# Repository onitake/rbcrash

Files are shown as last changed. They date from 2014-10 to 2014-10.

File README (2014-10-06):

Rainbow Crash
=============

Colorful illumination - it's 20% cooler.

0. Contents
-----------

0. Contents
1. Description
2. License
3. Tools
4. Assembly
5. Compilation
6. Use
7. References

1. Description
--------------

Rainbow Crash is a high power color LED driver suitable for indoor lighting
applications. It is based on the TPS61165 constant current step-up regulator,
driving a chain of 350mA RGB LEDs. In the default configuration, the input
voltage should be around 12V for 8 LEDs in series. Lower voltages are possible,
as long as they are not below about 4V, or the microcontroller and the drivers
will be underpowered. Higher voltages should only be chosen if more than 8 LEDs
are driven.

2. License
----------

The circuit design is released under the [CERN Open Hardware License v1.2][ohl].
The firmware is covered by the [two-clause BSD license][bsd].

All documents are copyright (c) 2012-2014 by Gregor Riepl <onitake@gmail.com>.

The latest version can be retrieved from [Github][github].

3. Tools
--------

The original circuit was designed using [Eagle][eagle]. An updated version of
the circuit (2.0) was remade in [KiCAD][kicad].
The firmware for the microcontroller is based on a simple Makefile,
[avr-gcc][avrgcc], avr-libc and [avrdude][avrdude].
The code should be easily adaptable to other Atmel toolchains.

No [Arduino][arduino] or other external libraries were used; however, the code
includes register definitions for the [Arduino Uno][uno] development platform.
It was during the design phase and for debugging.

4. Assembly
-----------

Except for the constant current drivers and the corresponding inductors, most
parts should be easily obtainable from any electronic parts distributor.
Some of the capacitors are also less common (10uF and 4.7uF SMD0805 ceramic),
as well as the shunt resistors (0.57Ohms 1/8W).
SMD0805/2012 was chosen due to good hand solderability and power rating.

The inductor pads are generously dimensioned so they may accomodate various
kinds of SMD inductors. The layout is based on Wuerth Electronics WE-PD M-sized
shielded inductors, which are readily available from [Digi-Key][digikey].
Their continuous current rating should be above 700mA, preferably around 1A.

The intended IR receiver is a standard 38kHz demodulator with AGC. Other
parts with similar specifications may be used; they are mostly compatible
with each other and various consumer remotes.

It is recommended to employ a reflow process if producing multiple driver
boards. For single pieces or prototypes, hand soldering is also possible.

Production runs should not include the ISP pin header P6. Instead, order the
ATtiny25 microcontrollers preprogrammed or use a temporary connector to
transfer the firmware.

5. Compilation
--------------

All source code is contained in the single file pwm.c. Compiling is easiest
with the [avr-gcc][avrgcc] toolchain and GNU make. If you would like to use
other tools, make sure that your compiler understands ISO C99.

To flash the firmware, the Makefile includes a `flash` target that executes
[avrdude][avrdude] using options for the tinyUSB AVR ISP programmer.
avrdude supports many different programmers, see the manual for the appropriate
options.

6. Use
------

pwm.c includes preprogrammed IR codes for an old infrared remote found in the
garbage. It sends (incorrect) NEC codes, so those are the only IR codes
currently supported by the firmware. Sony and RC5 codes are still being worked
on, as well as a test tool for the Arduino Uno and possibly a firmware
extension to support live programming.

7. References
-------------

[ohl]: LICENSE-HARDWARE
[bsd]: LICENSE-SOFTWARE
[github]: https://github.com/onitake/rbcrash
[eagle]: http://www.cadsoft.de
[kicad]: http://www.kicad-pcb.org
[arduino]: http://arduino.cc
[uno]: http://arduino.cc/en/Main/ArduinoBoardUno
[digikey]: http://www.digikey.com/catalog/en/partgroup/we-pd-series/38220
[avrgcc]: http://www.nongnu.org/avr-libc/
[avrdude]: http://www.nongnu.org/avrdude/

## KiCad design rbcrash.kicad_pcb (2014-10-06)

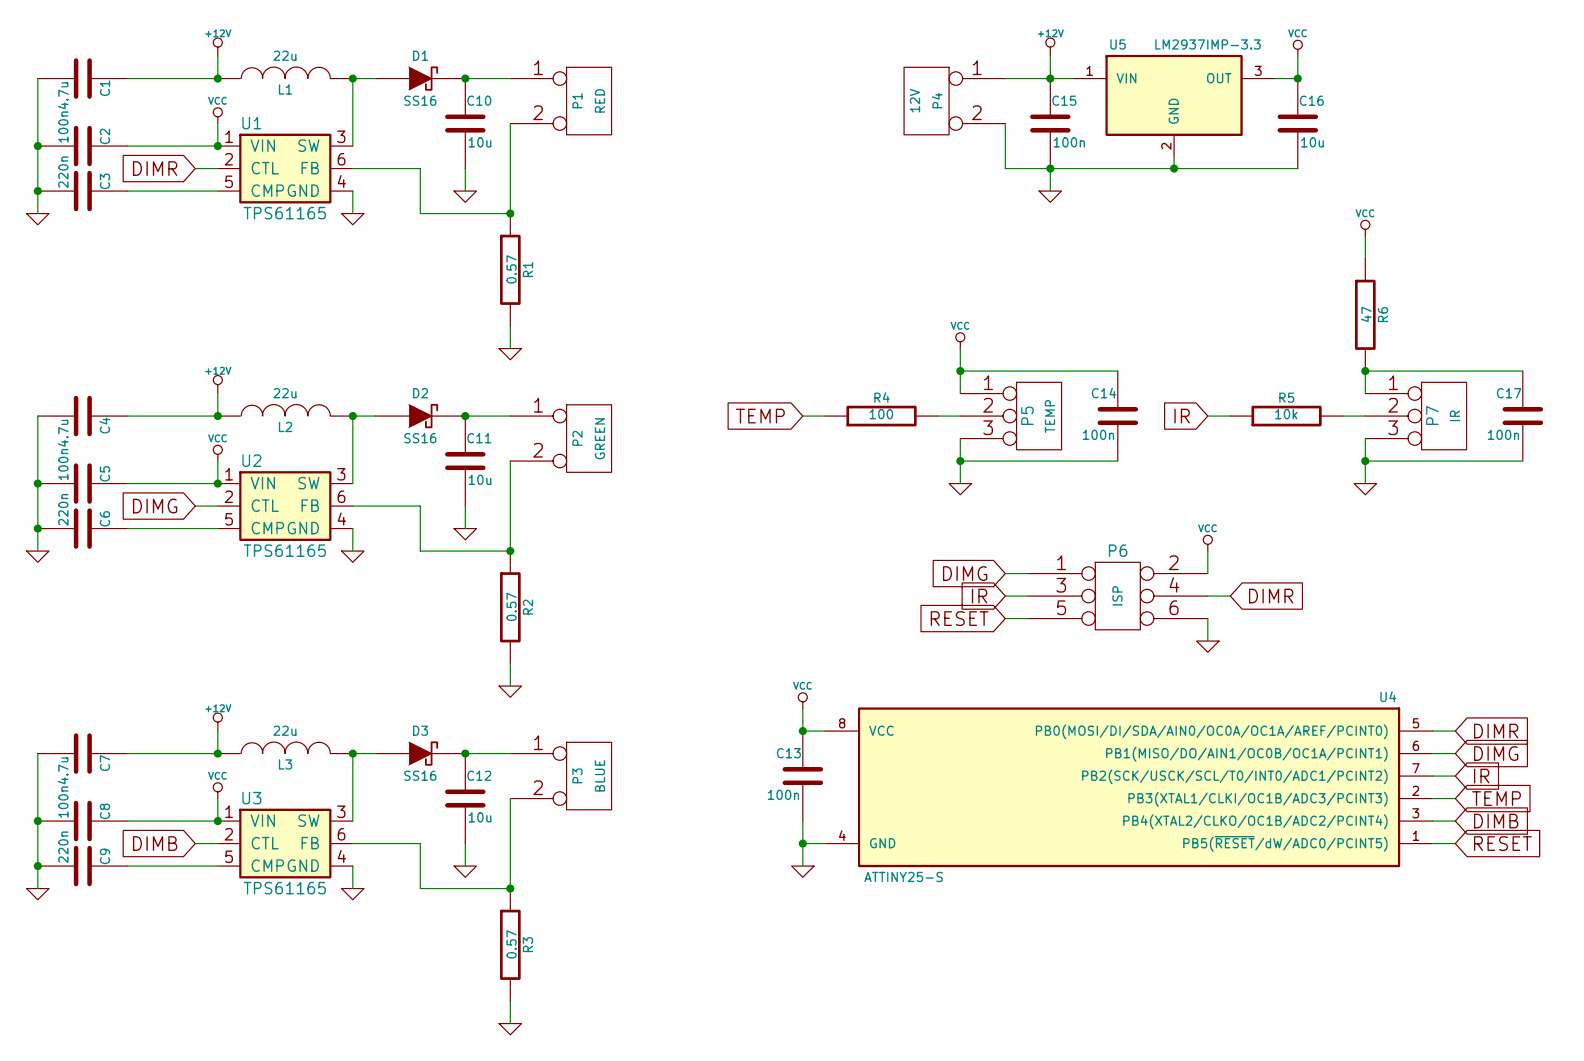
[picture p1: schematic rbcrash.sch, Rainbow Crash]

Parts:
C1, C4, C7: 4.7u; SM0805
C2, C5, C8, C13, C14, C15, C17: 100n; SM0805
C3, C6, C9: 220n; SM0805
C10, C11, C12, C16: 10u; SM0805
D1, D2, D3: SS16
L1, L2, L3: 22u
P1: RED
P2: GREEN
P3: BLUE
P4: 12V
P5: TEMP
P6: ISP
P7: IR
R1, R2, R3: 0.57; SM0805
R4: 100; SM0805
R5: 10k; SM0805
R6: 47; SM0805
U1, U2, U3: TPS61165
U4: ATTINY25-S; SO8-200
U5: LM2937IMP-3.3; SOT-223

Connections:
+12V: C1.1, C4.1, C7.1, C15.1, L1.1, L2.1, L3.1, P4.1, U5.1 (VIN)
DIMB: U3.2 (CTL), U4.3 (PB4(XTAL2/CLKO/OC1B/ADC2/PCINT4))
DIMG: P6.1, U2.2 (CTL), U4.6 (PB1(MISO/DO/AIN1/OC0B/OC1A/PCINT1))
DIMR: P6.4, U1.2 (CTL), U4.5 (PB0(MOSI/DI/SDA/AIN0/OC0A/OC1A/AREF/PCI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)
GND: C1.2, C2.2, C3.2, C4.2, C5.2, C6.2, C7.2, C8.2, C9.2, C10.2, C11.2, C12.2, C13.2, C14.2, C15.2, C16.2, C17.2, P4.2 (PM), P5.3, P6.6, P7.3, R1.2, R2.2, R3.2, U1.4 (GND), U2.4 (GND), U3.4 (GND), U4.4 (GND), U5.2 (GND)
IR: P6.3, R5.1, U4.7 (PB2(SCK/USCK/SCL/T0/INT0/ADC1/PCINT2))
unnamed: C12.1, D3.2 (K), P3.1
unnamed: C9.1, U3.5 (CMP)
unnamed: P3.2 (PM), R3.1, U3.6 (FB)
unnamed: D3.1 (A), L3.2, U3.3 (SW)
unnamed: P2.2 (PM), R2.1, U2.6 (FB)
unnamed: C6.1, U2.5 (CMP)
unnamed: C11.1, D2.2 (K), P2.1
unnamed: D2.1 (A), L2.2, U2.3 (SW)
unnamed: C17.1, P7.1, R6.2
unnamed: P7.2 (PM), R5.2
unnamed: P5.2 (PM), R4.2
unnamed: C3.1, U1.5 (CMP)
unnamed: C10.1, D1.2 (K), P1.1
unnamed: P1.2 (PM), R1.1, U1.6 (FB)
unnamed: D1.1 (A), L1.2, U1.3 (SW)
RESET: P6.5, U4.1 (PB5(~RESET~/dW/ADC0/PCINT5))
TEMP: R4.1, U4.2 (PB3(XTAL1/CLKI/OC1B/ADC3/PCINT3))
VCC: C2.1, C5.1, C8.1, C13.1, C14.1, C16.1, P5.1, P6.2, R6.1, U1.1 (VIN), U2.1 (VIN), U3.1 (VIN), U4.8 (VCC), U5.3 (OUT)

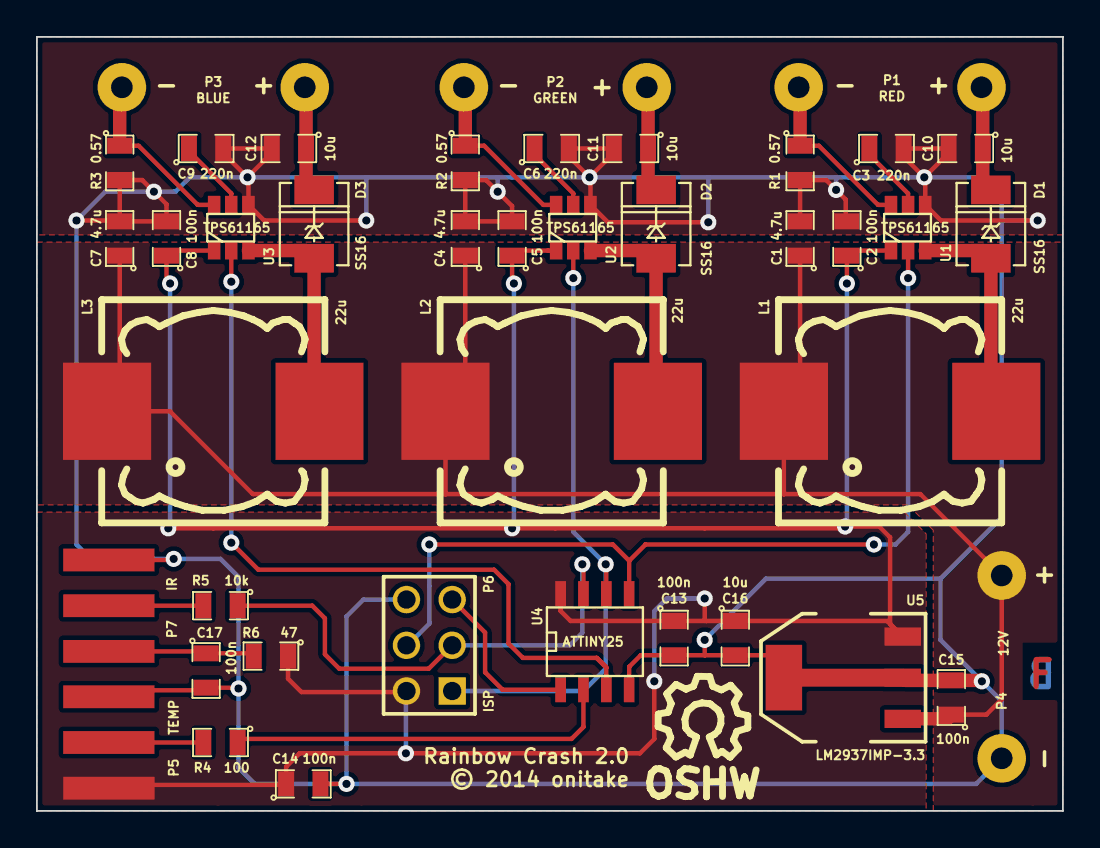
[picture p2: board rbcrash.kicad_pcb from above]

Board: 2 copper layers, 57.0 x 43.0 mm, 42 parts (0 on the bottom side), 24 nets.

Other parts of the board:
SYM: Symbol_OSHW-Logo_SilkScreen_07Jul2012

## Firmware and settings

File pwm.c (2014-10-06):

/*
 * rbcrash - Rainbow Crash LED driver firmware
 * 
 * Copyright (c) 2012-2014, Gregor Riepl <onitake@gmail.com>
 * All rights reserved.
 * 
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
 * THIS SOFTWARE IS PROVIDED BY THE COPYRIGHT HOLDERS AND CONTRIBUTORS "AS IS" AND
 * ANY EXPRESS OR IMPLIED WARRANTIES, INCLUDING, BUT NOT LIMITED TO, THE IMPLIED
 * WARRANTIES OF MERCHANTABILITY AND FITNESS FOR A PARTICULAR PURPOSE ARE
 * DISCLAIMED. IN NO EVENT SHALL THE COPYRIGHT HOLDER OR CONTRIBUTORS BE LIABLE FOR
 * ANY DIRECT, INDIRECT, INCIDENTAL, SPECIAL, EXEMPLARY, OR CONSEQUENTIAL DAMAGES
 * (INCLUDING, BUT NOT LIMITED TO, PROCUREMENT OF SUBSTITUTE GOODS OR SERVICES;
 * LOSS OF USE, DATA, OR PROFITS; OR BUSINESS INTERRUPTION) HOWEVER CAUSED AND ON
 * ANY THEORY OF LIABILITY, WHETHER IN CONTRACT, STRICT LIABILITY, OR TORT
 * (INCLUDING NEGLIGENCE OR OTHERWISE) ARISING IN ANY WAY OUT OF THE USE OF THIS
 * SOFTWARE, EVEN IF ADVISED OF THE POSSIBILITY OF SUCH DAMAGE.
 */

#include <inttypes.h>
#include <avr/io.h>
#include <avr/interrupt.h>
#include <avr/sleep.h>
#include <util/atomic.h>
#include <avr/io.h>
#include <util/delay.h>
#include <stdio.h>
#include <avr/pgmspace.h>
#include "clocks.h"

#if CLOCK_DIV >= 256 && CLOCK_DIV % 256 == 0
#define CLOCK0_DIV (CLOCK_DIV / 256)
#define CLOCK1_DIV (CLOCK_DIV / 256)
#define CLOCK_COUNT 1
#else
#error Invalid clock divider for IR decoder, an integer multiple of 256 is required
#endif

#ifdef F_IR_MIN
#if F_CPU / CLOCK0_DIV / 256 < F_IR_MIN
#error PWM frequency is too small, decrease the divider
#endif
#endif
#ifdef F_IR_MAX
#if F_CPU / CLOCK0_DIV / 256 > F_IR_MAX
#error PWM frequency is too big, increase the divider
#endif
#endif

#if defined(__AVR_ATtiny25__) || defined(__AVR_ATtiny45__) || defined(__AVR_ATtiny85__)

#if (CLOCK0_DIV == 0)
#define CLOCK0_CSX 0
#elif (CLOCK0_DIV == 1)
#define CLOCK0_CSX _BV(CS00)
#elif (CLOCK0_DIV == 8)
#define CLOCK0_CSX _BV(CS01)
#elif (CLOCK0_DIV == 64)
#define CLOCK0_CSX (_BV(CS00) | _BV(CS01))
#elif (CLOCK0_DIV == 256)
#define CLOCK0_CSX _BV(CS02)
#elif (CLOCK0_DIV == 1024)
#define CLOCK0_CSX (_BV(CS00) | _BV(CS02))
#else
#error Unsupported divider for timer 0
#endif

#define CLOCK0_TCCRA TCCR0A
#define CLOCK0_TCCRB TCCR0B
#define CLOCK0_TIMSK TIMSK
#define CLOCK0_TCNT TCNT0
#define CLOCK0_REGA (_BV(WGM00) | _BV(WGM01) | _BV(COM0A0) | _BV(COM0A1) | _BV(COM0B0) | _BV(COM0B1))
#define CLOCK0_REGB CLOCK0_CSX
#define CLOCK0_INTS _BV(TOIE0)
#define CLOCK0_OVERFLOW_INTVECT TIMER0_OVF_vect

#if (CLOCK1_DIV == 0)
#define CLOCK1_CSX 0
#elif (CLOCK1_DIV == 1)
#define CLOCK1_CSX _BV(CS10)
#elif (CLOCK1_DIV == 2)
#define CLOCK1_CSX _BV(CS11)
#elif (CLOCK1_DIV == 4)
#define CLOCK1_CSX (_BV(CS10) | _BV(CS11))
#elif (CLOCK1_DIV == 8)
#define CLOCK1_CSX _BV(CS12)
#elif (CLOCK1_DIV == 16)
#define CLOCK1_CSX (_BV(CS10) | _BV(CS12))
#elif (CLOCK1_DIV == 32)
#define CLOCK1_CSX (_BV(CS11) | _BV(CS12))
#elif (CLOCK1_DIV == 64)
#define CLOCK1_CSX (_BV(CS10) | _BV(CS11) | _BV(CS12))
#elif (CLOCK1_DIV == 128)
#define CLOCK1_CSX _BV(CS13)
#elif (CLOCK1_DIV == 256)
#define CLOCK1_CSX (_BV(CS10) | _BV(CS13))
#elif (CLOCK1_DIV == 512)
#define CLOCK1_CSX (_BV(CS11) | _BV(CS13))
#elif (CLOCK1_DIV == 1024)
#define CLOCK1_CSX (_BV(CS10) | _BV(CS11) | _BV(CS13))
#elif (CLOCK1_DIV == 2048)
#define CLOCK1_CSX (_BV(CS12) | _BV(CS13))
#elif (CLOCK1_DIV == 4096)
#define CLOCK1_CSX (_BV(CS10) | _BV(CS12) | _BV(CS13))
#elif (CLOCK1_DIV == 8192)
#define CLOCK1_CSX (_BV(CS11) | _BV(CS12) | _BV(CS13))
#elif (CLOCK1_DIV == 16384)
#define CLOCK1_CSX (_BV(CS10) | _BV(CS11) | _BV(CS12) | _BV(CS13))
#else
#error Unsupported divider for timer 1
#endif

#define CLOCK1_TCCRA TCCR1
#define CLOCK1_TCCRB GTCCR
#define CLOCK1_TIMSK TIMSK
#define CLOCK1_TCNT TCNT1
#define CLOCK1_REGA CLOCK1_CSX
#define CLOCK1_REGB (_BV(PWM1B) | _BV(COM1B0))
#define CLOCK1_INTS 0
#define CLOCK1_OVERFLOW_INTVECT TIMER2_OVF_vect

#define PWM_OCR_RED OCR0A
#define PWM_OCR_GREEN OCR0B
#define PWM_OCR_BLUE OCR1B
#define PWM_PORT PORTB
#define PWM_DDR DDRB
#define PWM_PIN PINB
#define PWM_MASK (_BV(0) | _BV(1) | _BV(4))
#define PWM_INV_RED 1
#define PWM_INV_GREEN 1
#define PWM_INV_BLUE 0

#define IR_PIN PINB
#define IR_DDR DDRB
#define IR_PORT PORTB
#define IR_BIT _BV(DDB2)
#define IR_INT _BV(PCINT2)
#define IR_PCMSK PCMSK
#define IR_GIMSK GIMSK
#define IR_PCIE _BV(PCIE)
#define IR_INTVECT PCINT0_vect

#elif defined(__AVR_ATmega328__) || defined(__AVR_ATmega328P__)

#if (CLOCK0_DIV == 0)
#define CLOCK0_CSX 0
#elif (CLOCK0_DIV == 1)
#define CLOCK0_CSX _BV(CS00)
#elif (CLOCK0_DIV == 8)
#define CLOCK0_CSX _BV(CS01)
#elif (CLOCK0_DIV == 64)
#define CLOCK0_CSX (_BV(CS00) | _BV(CS01))
#elif (CLOCK0_DIV == 256)
#define CLOCK0_CSX _BV(CS02)
#elif (CLOCK0_DIV == 1024)
#define CLOCK0_CSX (_BV(CS00) | _BV(CS02))
#else
#error Unsupported divider for timer 0
#endif

#define CLOCK0_TCCRA TCCR0A
#define CLOCK0_TCCRB TCCR0B
#define CLOCK0_TIMSK TIMSK0
#define CLOCK0_TCNT TCNT0
#define CLOCK0_REGA (_BV(WGM00) | _BV(WGM01) | _BV(COM0A0) | _BV(COM0A1) | _BV(COM0B0) | _BV(COM0B1))
#define CLOCK0_REGB CLOCK0_CSX
#define CLOCK0_INTS _BV(TOIE0)
#define CLOCK0_OVERFLOW_INTVECT TIMER0_OVF_vect

#if (CLOCK1_DIV == 0)
#define CLOCK1_CSX 0
#elif (CLOCK1_DIV == 1)
#define CLOCK1_CSX _BV(CS20)
#elif (CLOCK1_DIV == 8)
#define CLOCK1_CSX _BV(CS21)
#elif (CLOCK1_DIV == 32)
#define CLOCK1_CSX (_BV(CS20) | _BV(CS21))
#elif (CLOCK1_DIV == 64)
#define CLOCK1_CSX _BV(CS22)
#elif (CLOCK1_DIV == 128)
#define CLOCK1_CSX (_BV(CS20) | _BV(CS22))
#elif (CLOCK1_DIV == 256)
#define CLOCK1_CSX (_BV(CS21) | _BV(CS22))
#elif (CLOCK1_DIV == 1024)
#define CLOCK1_CSX (_BV(CS20) | _BV(CS21) | _BV(CS22))
#else
#error Unsupported divider for timer 1
#endif

#define CLOCK1_TCCRA TCCR2A
#define CLOCK1_TCCRB TCCR2B
#define CLOCK1_TIMSK TIMSK2
#define CLOCK1_TCNT TCNT2
#define CLOCK1_REGA (_BV(WGM20) | _BV(WGM21) | _BV(COM2B0) | _BV(COM2B1))
#define CLOCK1_REGB CLOCK1_CSX
#define CLOCK1_INTS 0
#define CLOCK1_OVERFLOW_INTVECT TIMER2_OVF_vect

#define PWM_OCR_RED OCR2B
#define PWM_OCR_GREEN OCR0A
#define PWM_OCR_BLUE OCR0B
#define PWM_PORT PORTD
#define PWM_DDR DDRD
#define PWM_PIN PIND
#define PWM_MASK (_BV(3) | _BV(5) | _BV(6))
#define PWM_INV_RED 1
#define PWM_INV_GREEN 1
#define PWM_INV_BLUE 1

#define IR_PIN PIND
#define IR_DDR DDRD
#define IR_PORT PORTD
#define IR_BIT _BV(DDD2)
#define IR_INT _BV(PCINT18)
#define IR_PCMSK PCMSK2
#define IR_GIMSK PCICR
#define IR_PCIE _BV(PCIE2)
#define IR_INTVECT PCINT2_vect

#else
#error Unknown architecture, please add support for your MCU in pwm.c
#endif

#define COLOR_RED_MAX 32
#define COLOR_GREEN_MAX 32
#define COLOR_BLUE_MAX 32

#define COLOR_RED color_make(255, 0, 0)
#define COLOR_GREEN color_make(0, 255, 0)
#define COLOR_BLUE color_make(0, 0, 255)
#define COLOR_YELLOW color_make(255, 255, 0)
#define COLOR_CYAN color_make(0, 255, 255)
#define COLOR_MAGENTA color_make(255, 0, 255)
#define COLOR_BLACK color_make(0, 0, 0)
#define COLOR_WHITE color_make(255, 255, 255)

#define CHANGE_STATE(stat, clk) { global.state = stat; }
#define CLOCK_MATCH(symbol, diff) (CLOCK_##symbol##_MIN <= diff && diff < CLOCK_##symbol##_MAX)
#define DEBUG_ERROR(err, cod, clk)

#if CLOCK_16BIT
typedef uint16_t clock_t;
#else
typedef uint8_t clock_t;
#endif

typedef struct {
	uint8_t r, g, b;
} color_t;

enum {
	// No code received
	IR_CODE_NONE,
	// Sony IR codes (SIRC)
	IR_CODE_SONY12,
	IR_CODE_SONY15,
	IR_CODE_SONY20,
	// Philips IR code (RC5)
	IR_CODE_RC5,
	// NEC IR code
	IR_CODE_NEC,
#if ENABLE_DEBUG
	// Errors (only generated in debug mode)
	// Unknown/invalid pulse (clk contains the pulse length)
	IR_ERROR_PULSE,
	// Checksum mismatch or other transmission error
	IR_ERROR_TRANSMISSION,
	// Glitch detected
	IR_ERROR_GLITCH,
	// Unimplemented decoding routine
	IR_ERROR_UNIMPLEMENTED,
	// Invalid state (i.e. repeat without corresponding code to repeat)
	IR_ERROR_STATE,
	// Interrupt event overrun
	IR_ERROR_OVERRUN,
	// Debug events
	// Report state change (state contains the old and new states)
	IR_DEBUG_STATE,
#endif
};

typedef struct {
	uint8_t type;
	union {
#if ENABLE_SIRC
		struct {
			uint8_t code;
			uint8_t device;
			uint8_t extend;
		} sony;
#endif
		uint8_t rc5;
#if ENABLE_NEC
		struct {
			uint8_t device;
			uint8_t code;
			uint8_t repeat:1;
			uint8_t verified:1;
		} nec;
#endif
#if 0 && ENABLE_DEBUG
		struct {
			uint16_t code;
			clock_t clock;
			uint16_t line;
		} error;
		struct {
			uint8_t old;
			uint8_t new;
			clock_t clock;
			uint16_t line;
		} state;
#endif
	} code;
} irevent_t;

// State machine
enum {
	IR_STATE_IDLE,
	IR_STATE_START,
	IR_STATE_SIRC_START_ACK,
	IR_STATE_SIRC_BIT,
	IR_STATE_SIRC_ACK,
	IR_STATE_NEC_TYPE,
	IR_STATE_NEC_CMD_ACK,
	IR_STATE_NEC_RPT_ACK,
	IR_STATE_NEC_BIT,
	IR_STATE_NEC_SHORT_ACK,
	IR_STATE_NEC_LONG_ACK,
};

// Interrupt handler states
enum {
	IR_INTSTATE_IDLE,
	IR_INTSTATE_L_TO_H,
	IR_INTSTATE_H_TO_L,
	IR_INTSTATE_GLITCH,
	IR_INTSTATE_OVERRUN,
	IR_INTSTATE_DONE,
	IR_INTSTATE_SIRC_DONE,
	IR_INTSTATE_TIMEOUT,
};

const PROGMEM uint8_t PWM_LOOKUP[32] = { 0, 1, 4, 7, 11, 15, 20, 26, 32, 38, 44, 51, 58, 66, 74, 82, 90, 99, 108, 117, 126, 136, 145, 155, 166, 176, 187, 198, 209, 220, 232, 244, };

static volatile struct {
	// Current wall clock in tPWM/256 units
	clock_t clock;
	// Last port level (0 = L, 1 = H)
	uint8_t bitstate;
	// Interrupt handler state
	uint8_t intstate;
	// Flag telling if a bit change or glitch event is pending
	uint8_t pending;
	// Timestamp of previous interrupt event
	clock_t prevclock;
	// Timestamp of last interrupt event
	clock_t lastclock;
	// State machine state
	uint8_t state;
	// Detected code type (or IR_CODE_NONE if no code stored)
	uint8_t type;
	// Shift register
	uint32_t word;
	// Number of bits in shift register
	uint8_t bitcount;
	// Data store (for repeats)
	union {
		uint32_t init;
		struct {
			uint8_t device;
			uint8_t code;
			uint8_t verified:1;
		} nec;
	} data;
} global __attribute__((section(".noinit")));

static clock_t clock_now();

ISR(CLOCK0_OVERFLOW_INTVECT) {
	global.clock++;
}

ISR(IR_INTVECT) {
	// Read IR pin state first to avoid additional glitches
	uint8_t bit = IR_PIN & IR_BIT;
	
	// Interrupt glitch detection
	if (bit != global.bitstate) {
		// Record the bit change
		global.bitstate = bit;
		
		// Check if an event is already pending
		if (!global.pending) {
			// Copy the last clock event to the previous one
			global.prevclock = global.lastclock;
			// Get the current time
			global.lastclock = clock_now();
			
			// Post the event
			global.intstate = bit ? IR_INTSTATE_L_TO_H : IR_INTSTATE_H_TO_L;
		} else {
			// Report an overrun
			global.intstate = IR_INTSTATE_OVERRUN;
		}
	} else {
		// Check if an event is already pending
		if (!global.pending) {
			// Report a glitch
			global.intstate = IR_INTSTATE_GLITCH;
		} else {
			// Report an overrun
			global.intstate = IR_INTSTATE_OVERRUN;
		}
	}
	
	// Signal the new event
	global.pending = 1;
}

static void clock_init() {
	global.clock = 0;
	CLOCK0_TCNT = 0;
	CLOCK1_TCNT = 0;
#ifdef CLOCK0_TOP
	CLOCK0_TOP = 255;
#endif
#ifdef CLOCK1_TOP
	CLOCK1_TOP = 255;
#endif
	CLOCK0_TIMSK |= CLOCK0_INTS;
	CLOCK1_TIMSK |= CLOCK1_INTS;
	CLOCK0_TCCRA = CLOCK0_REGA;
	CLOCK0_TCCRB = CLOCK0_REGB;
	CLOCK1_TCCRA = CLOCK1_REGA;
	CLOCK1_TCCRB = CLOCK1_REGB;
}

static clock_t clock_now() {
	return global.clock / CLOCK_COUNT;
}

static color_t color_make(uint8_t r, uint8_t g, uint8_t b) {
	color_t c = { r, g, b };
	return c;
}

static void color_set(color_t unscaled) {
	color_t c = color_make(unscaled.r < COLOR_RED_MAX ? pgm_read_byte(&PWM_LOOKUP[unscaled.r]) : 255, unscaled.g < COLOR_GREEN_MAX ? pgm_read_byte(&PWM_LOOKUP[unscaled.g]) : 255, unscaled.b < COLOR_BLUE_MAX ? pgm_read_byte(&PWM_LOOKUP[unscaled.b]) : 255);
#if PWM_INV_RED
	PWM_OCR_RED = ~c.r;
#else
	PWM_OCR_RED = c.r;
#endif
#if PWM_INV_GREEN
	PWM_OCR_GREEN = ~c.g;
#else
	PWM_OCR_GREEN = c.g;
#endif
#if PWM_INV_BLUE
	PWM_OCR_BLUE = ~c.b;
#else
	PWM_OCR_BLUE = c.b;
#endif
}

static color_t color_get() {
	color_t ret;
#if PWM_INV_RED
	ret.r = ~PWM_OCR_RED;
#else
	ret.r = PWM_OCR_RED;
#endif
#if PWM_INV_GREEN
	ret.g = ~PWM_OCR_GREEN;
#else
	ret.g = PWM_OCR_GREEN;
#endif
#if PWM_INV_BLUE
	ret.b = ~PWM_OCR_BLUE;
#else
	ret.b = PWM_OCR_BLUE;
#endif
	return ret;
}

static void color_init() {
	color_set(COLOR_BLACK);
	PWM_PORT &= ~PWM_MASK;
	PWM_DDR |= PWM_MASK;
}

static void ir_init() {
	IR_DDR &= ~IR_BIT;
	IR_PORT |= IR_BIT;
	global.pending = 0;
	global.intstate = IR_INTSTATE_IDLE;
	global.lastclock = clock_now();
	global.prevclock = global.lastclock;
	// Initialize code detector state
	CHANGE_STATE(IR_STATE_IDLE, 0);
	global.type = IR_CODE_NONE;
	global.word = 0;
	global.bitcount = 0;
	global.data.init = 0;
	global.bitstate = IR_PIN & IR_BIT;
	IR_PCMSK |= IR_INT;
	IR_GIMSK |= IR_PCIE;
}

irevent_t ir_handle() {
	// Check if we have an event pending
	uint8_t pending;
	uint8_t intstate;
	clock_t clockdiff;
	ATOMIC_BLOCK(ATOMIC_RESTORESTATE) {
		pending = global.pending;
		intstate = global.intstate;
		global.pending = 0;
		global.intstate = IR_INTSTATE_IDLE;
		clockdiff = global.lastclock - global.prevclock;
	}
	if (pending) {
		/* Debug */ //{ irevent_t ev = { .type = IR_CODE_NEC, .code = { .nec = { .device = (uint8_t) (clockdiff >> 8), .code = (uint8_t) clockdiff } } }; return ev; }
		
		// Determine the type of interrupt event
		switch (intstate) {
			case IR_INTSTATE_IDLE:
				// Ignore
				break;
			case IR_INTSTATE_L_TO_H:
			case IR_INTSTATE_H_TO_L:
				switch (global.state) {
					case IR_STATE_IDLE:
						CHANGE_STATE(IR_STATE_START, clockdiff);
						break;
					case IR_STATE_START:
#if ENABLE_NEC
						if (CLOCK_MATCH(NEC_START, clockdiff)) {
							CHANGE_STATE(IR_STATE_NEC_TYPE, clockdiff);
						} else
#endif
#if ENABLE_SIRC
						if (CLOCK_MATCH(SIRC_START, clockdiff)) {
							CHANGE_STATE(IR_STATE_SIRC_START_ACK, clockdiff);
						} else
#endif
						{
							CHANGE_STATE(IR_STATE_IDLE, clockdiff);
							DEBUG_ERROR(IR_ERROR_PULSE, 0, clockdiff);
						}
						break;
#if ENABLE_NEC
					case IR_STATE_NEC_TYPE:
						if (CLOCK_MATCH(NEC_MODE_CMD, clockdiff)) {
							CHANGE_STATE(IR_STATE_NEC_CMD_ACK, clockdiff);
						} else if (CLOCK_MATCH(NEC_MODE_REP, clockdiff)) {
							CHANGE_STATE(IR_STATE_NEC_RPT_ACK, clockdiff);
						} else {
							CHANGE_STATE(IR_STATE_IDLE, clockdiff);
							DEBUG_ERROR(IR_ERROR_PULSE, 0, clockdiff);
						}
						break;
					case IR_STATE_NEC_CMD_ACK:
						if (CLOCK_MATCH(NEC_ACK, clockdiff)) {
							global.word = 0;
							global.bitcount = 0;
							global.type = IR_CODE_NONE;
							CHANGE_STATE(IR_STATE_NEC_BIT, clockdiff);
						} else {
							CHANGE_STATE(IR_STATE_IDLE, clockdiff);
							DEBUG_ERROR(IR_ERROR_PULSE, 0, clockdiff);
						}
						break;
					case IR_STATE_NEC_RPT_ACK:
						if (CLOCK_MATCH(NEC_ACK, clockdiff)) {
							if (global.type == IR_CODE_NEC) {
								CHANGE_STATE(IR_STATE_IDLE, clockdiff);
								{ irevent_t ev = { .type = IR_CODE_NEC, .code = { .nec = { .repeat = 1, .verified = global.data.nec.verified, .device = global.data.nec.device, .code = global.data.nec.code } } }; return ev; }
							} else {
								CHANGE_STATE(IR_STATE_IDLE, clockdiff);
								DEBUG_ERROR(IR_ERROR_STATE, IR_STATE_NEC_RPT_ACK, clockdiff);
							}
						} else {
							CHANGE_STATE(IR_STATE_IDLE, clockdiff);
							DEBUG_ERROR(IR_ERROR_PULSE, 0, clockdiff);
						}
						break;
					case IR_STATE_NEC_BIT:
						if (CLOCK_MATCH(NEC_LONG, clockdiff)) {
							CHANGE_STATE(IR_STATE_NEC_LONG_ACK, clockdiff);
						} else if (CLOCK_MATCH(NEC_SHORT, clockdiff)) {
							CHANGE_STATE(IR_STATE_NEC_SHORT_ACK, clockdiff);
						} else {
							CHANGE_STATE(IR_STATE_IDLE, clockdiff);
							DEBUG_ERROR(IR_ERROR_PULSE, 0, clockdiff);
						}
						break;
					case IR_STATE_NEC_LONG_ACK:
						if (CLOCK_MATCH(NEC_ACK, clockdiff)) {
							// Store 1
							global.word = (global.word << 1) | 1;
							global.bitcount++;
							// Check for completion
							if (global.bitcount >= 32) {
								global.type = IR_CODE_NEC;
								global.data.nec.device = global.word >> 24;
								global.data.nec.code = global.word >> 8;
#if VERIFY_CHECKSUM
								// Evaluate checksum
								if ((uint8_t) (global.word >> 24) == (uint8_t) ~(global.word >> 16) && (uint8_t) (global.word >> 8) == (uint8_t) ~global.word) {
									global.data.nec.verified = 1;
								}
#endif
								CHANGE_STATE(IR_STATE_IDLE, clockdiff);
								{ irevent_t ev = { .type = IR_CODE_NEC, .code = { .nec = { .repeat = 0, .verified = global.data.nec.verified, .device = global.data.nec.device, .code = global.data.nec.code } } }; return ev; }
							} else {
								CHANGE_STATE(IR_STATE_NEC_BIT, clockdiff);
							}
						} else {
							CHANGE_STATE(IR_STATE_IDLE, clockdiff);
							DEBUG_ERROR(IR_ERROR_PULSE, 0, clockdiff);
						}
						break;
					case IR_STATE_NEC_SHORT_ACK:
						if (CLOCK_MATCH(NEC_ACK, clockdiff)) {
							// Store 0
							global.word = global.word << 1;
							global.bitcount++;
							// Check for completion
							if (global.bitcount >= 32) {
								global.type = IR_CODE_NEC;
								global.data.nec.device = global.word >> 24;
								global.data.nec.code = global.word >> 8;
#if VERIFY_CHECKSUM
								// Evaluate checksum
								if ((uint8_t) (global.word >> 24) == (uint8_t) ~(global.word >> 16) && (uint8_t) (global.word >> 8) == (uint8_t) ~global.word) {
									global.data.nec.verified = 1;
								}
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
int main() {
	color_init();
	clock_init();
	ir_init();
#if ENABLE_DEBUG
	serial_init(38400, 8, 1, 0);
#endif
	
	uint8_t rbon = 0;
	//color_t color = color_make(1.0 * COLOR_RED_MAX, 0.4 * COLOR_GREEN_MAX, 0 * COLOR_BLUE_MAX);
	color_t color = COLOR_BLACK;
	color_set(color);

	set_sleep_mode(SLEEP_MODE_IDLE);
	sei();

	debug("start=%u ack=%u cmd=%u rep=%u long=%u short=%u\n", CLOCK_NEC_START, CLOCK_NEC_ACK, CLOCK_NEC_MODE_CMD, CLOCK_NEC_MODE_REP, CLOCK_NEC_LONG, CLOCK_NEC_SHORT);

	while (1) {
		irevent_t ev = ir_handle();
		if (ev.type == IR_CODE_NEC) {
			debug("nec repeat=%u verified=%u device=%u code=%u\n", ev.code.nec.repeat, ev.code.nec.verified, ev.code.nec.device, ev.code.nec.code);
		}
#if ENABLE_DEBUG
		while (serial_rx_done()) {
			char c = serial_read();
			serial_write(c);
			if (c == '\r') serial_write('\n');
		}
#endif
#if ENABLE_SIRC
		if (ev.type == IR_CODE_SONY20 && ev.code.sony.device == 26) {
			switch (ev.code.sony.code) {
				case 92:
					// Square
					if (color.r < 31) color.r++;
					break;
				case 95:
					// Circle
					if (color.r > 0) color.r--;
					break;
				case 84:
					// Up
					if (color.g < 31) color.g++;
					break;
				case 86:
					// Down
					if (color.g > 0) color.g--;
					break;
				case 93:
					// Triangle
					if (color.b < 31) color.b++;
					break;
				case 94:
					// Cross
					if (color.b > 0) color.b--;
					break;
				case 11:
					// Ok
					rbon = 0;
					break;
				case 50:
					// Play
					rbon = 1;
					break;
			}
			color_set(color);
		}
#endif
#if ENABLE_NEC
		if (ev.type == IR_CODE_NEC && ev.code.nec.device == 225) {
			switch (ev.code.nec.code) {
				case 232:
					// Power
					if (!ev.code.nec.repeat) {
						color = COLOR_BLACK;
					}
					break;
				case 164:
					// Previous
					if (color.r > 0) color.r--;
					break;
				case 36:
					// Next
					if (color.r < COLOR_RED_MAX) color.r++;
					break;
				case 16:
					// Volume Up
					break;
				case 32:
					// Volume Down
					break;
				case 148:
					// Mute
					break;
				case 212:
					// Effect
					if (color.g > 0) color.g--;
					break;
				case 140:
					// Blank
					if (color.b > 0) color.b--;
					break;
				case 88:
					// Video
					if (color.g < COLOR_GREEN_MAX) color.g++;
					break;
				case 152:
					// Computer
					if (color.b < COLOR_BLUE_MAX) color.b++;
					break;
				case 200:
					// Up
					break;
				case 40:
					// Down
					break;
				case 64:
					// Menu
					break;
				case 76:
					// Select
					break;
			}
			color_set(color);
		}
#endif
		sleep_mode();
	}
	return 0;
}

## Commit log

2014-10-06 Redesign of circuit in KiCAD
    [rbcrash.kicad_pcb, rbcrash.sch]
2014-10-06 Rewrote most of the code, using the ATtiny's PWM generators now.

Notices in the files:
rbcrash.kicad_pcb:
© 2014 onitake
